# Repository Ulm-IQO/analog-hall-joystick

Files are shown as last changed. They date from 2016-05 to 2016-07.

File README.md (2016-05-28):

# Adjustable, Analog Hall Joystick

This joystick was designed to replace the failing resisitve joystick of a 
PI Micos SMC Corvus eco three-axis stepper motor controller.

The design has a primary XYZ joystick (Apem HF46S10) where the Z axis is 
the rotatable shaft and a secondary stick (Apem BF150A01BK0500) only 
for the Z axis.

Which Z axis is applied at the analog output can be controlled with a switch
while all four signals are available at the analog inputs of the integrated
Teensy 3.x microcontroller board.

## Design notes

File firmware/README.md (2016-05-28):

# Test program
Use Teensyduino to build and upload the test program to a Teensy 3.x
microcontroller board attached to the joystick board.

The values from the serial console can be used to adjust the potentiometers
for the gain and offset stages.

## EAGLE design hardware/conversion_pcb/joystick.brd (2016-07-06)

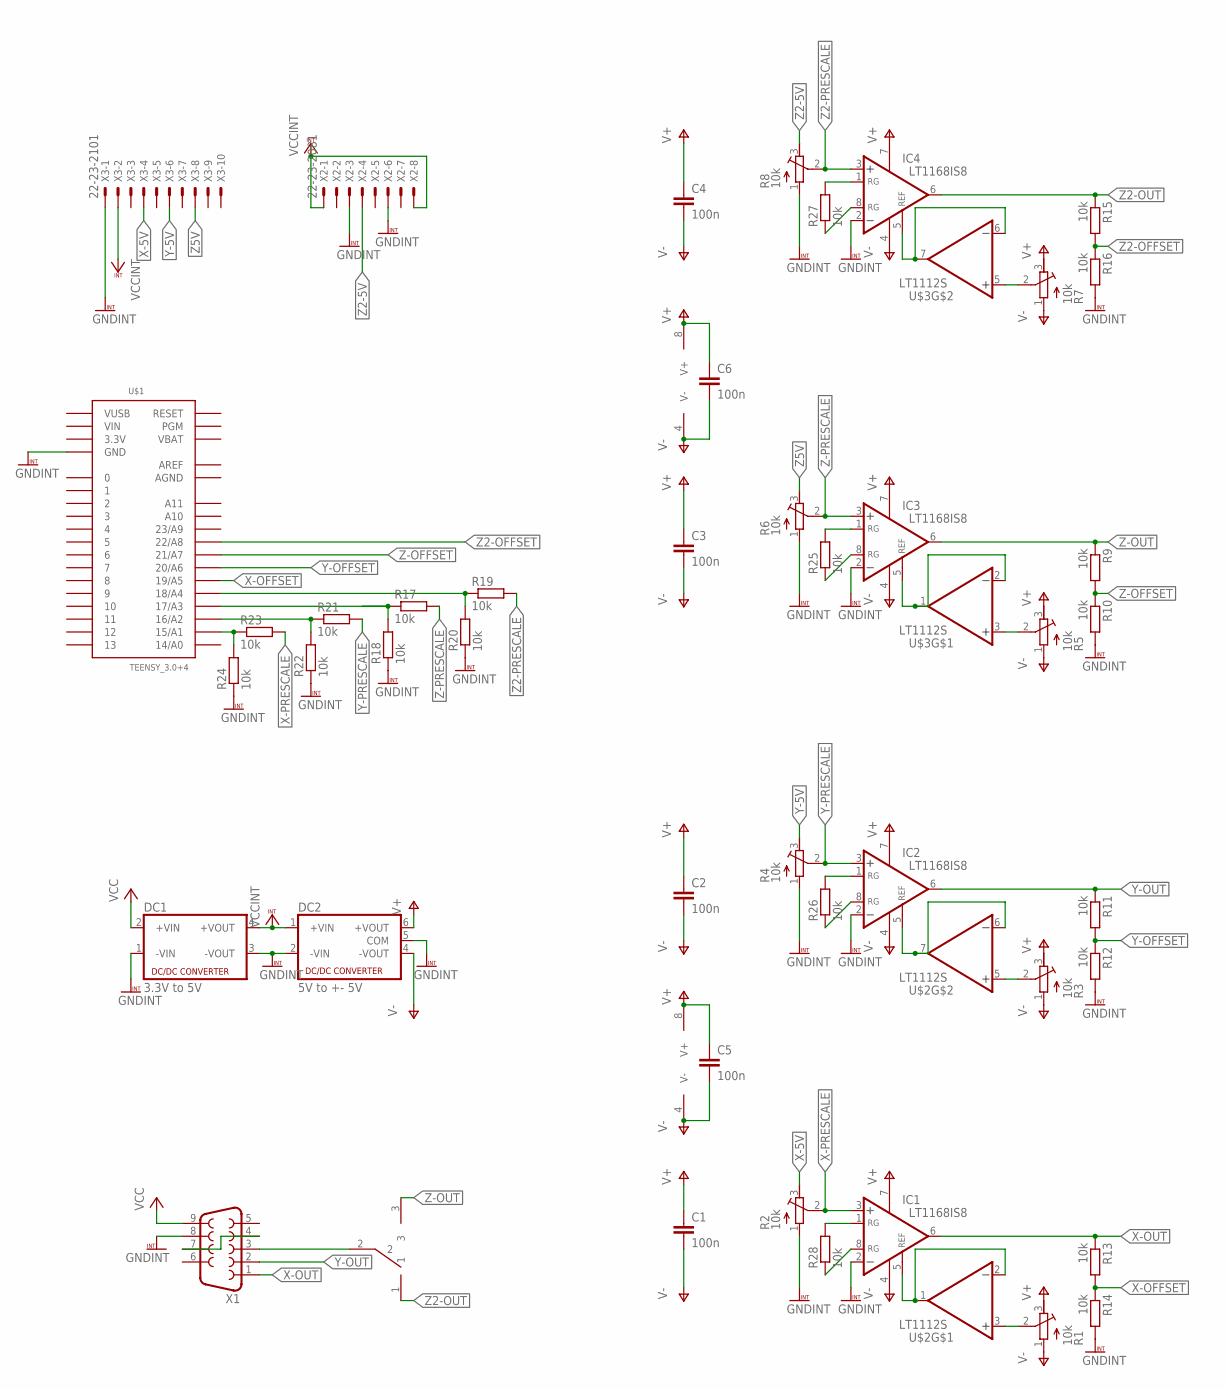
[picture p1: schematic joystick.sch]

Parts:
C1, C2, C3, C4, C5, C6: 100n; C1206
DC1: 3.3V to 5V; NME
DC2: 5V to +- 5V; NMA
IC1, IC2, IC3, IC4: LT1168IS8; SOIC8
R1, R2, R3, R4, R5, R6, R7, R8: 10k; RTRIM64W
R9, R10, R11, R12, R13, R14, R15, R16, R17, R18, R19, R20, R21, R22, R23, R24, R25, R26, R27, R28: 10k; R1206
U$1: TEENSY_3.0+4
U$2, U$3: LT1112S; SOIC8
U$4: MS12ASG40
X1: F09HP
X2: 22-23-2081
X3: 22-23-2101

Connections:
3.3V: U$1.3.3V, U$1.3.3V1 (3.3V)
AGND: U$1.AGND
AREF: U$1.AREF
GNDINT: DC1.1 (-VIN), DC1.3 (-VOUT), DC2.2 (-VIN), DC2.5 (COM), IC1.2 (-IN), IC2.2 (-IN), IC3.2 (-IN), IC4.2 (-IN), R2.1 (A), R4.1 (A), R6.1 (A), R8.1 (A), R10.2, R12.2, R14.2, R16.2, R18.1, R20.1, R22.1, R24.1, U$1.GND, U$1.GND1 (GND), X1.8, X2.3, X2.6, X3.1
unnamed: R1.2 (S), U$2.3 (+IN)
unnamed: R3.2 (S), U$2.5 (+IN)
unnamed: R5.2 (S), U$3.3 (+IN)
unnamed: R7.2 (S), U$3.5 (+IN)
unnamed: IC1.5 (REF), U$2.1 (OUT), U$2.2 (-IN)
unnamed: IC2.5 (REF), U$2.6 (-IN), U$2.7 (OUT)
unnamed: IC3.5 (REF), U$3.1 (OUT), U$3.2 (-IN)
unnamed: IC4.5 (REF), U$3.6 (-IN), U$3.7 (OUT)
unnamed: X1.4, X1.7
unnamed: U$4.2, X1.3
unnamed: R17.1, R18.2, U$1.17/A3
unnamed: R19.1, R20.2, U$1.18/A4
unnamed: R21.1, R22.2, U$1.16/A2
unnamed: R23.1, R24.2, U$1.15/A1
unnamed: IC1.8 (RG), R28.1
unnamed: IC1.1 (RG), R28.2
unnamed: IC2.1 (RG), R26.2
unnamed: IC2.8 (RG), R26.1
unnamed: IC3.1 (RG), R25.2
unnamed: IC3.8 (RG), R25.1
unnamed: IC4.8 (RG), R27.1
unnamed: IC4.1 (RG), R27.2
V+: C1.1, C2.1, C3.1, C4.1, C5.1, C6.1, DC2.6 (+VOUT), IC1.7 (V+), IC2.7 (V+), IC3.7 (V+), IC4.7 (V+), R1.3 (E), R3.3 (E), R5.3 (E), R7.3 (E), U$2.8 (V+), U$3.8 (V+)
V-: C1.2, C2.2, C3.2, C4.2, C5.2, C6.2, DC2.4 (-VOUT), IC1.4 (V-), IC2.4 (V-), IC3.4 (V-), IC4.4 (V-), R1.1 (A), R3.1 (A), R5.1 (A), R7.1 (A), U$2.4 (V-), U$3.4 (V-)
VBAT: U$1.VBAT
VCC: DC1.2 (+VIN), X1.9
VCCINT: DC1.4 (+VOUT), DC2.1 (+VIN), X2.1, X2.8, X3.2
VIN: U$1.VIN
VUSB: U$1.VUSB
X-5V: R2.3 (E), X3.4
X-OFFSET: R13.2, R14.1, U$1.19/A5
X-OUT: IC1.6 (OUT), R13.1, X1.1
X-PRESCALE: IC1.3 (+IN), R2.2 (S), R23.2
Y-5V: R4.3 (E), X3.6
Y-OFFSET: R11.2, R12.1, U$1.20/A6
Y-OUT: IC2.6 (OUT), R11.1, X1.2
Y-PRESCALE: IC2.3 (+IN), R4.2 (S), R21.2
Z2-5V: R8.3 (E), X2.4
Z2-OFFSET: R15.2, R16.1, U$1.22/A8
Z2-OUT: IC4.6 (OUT), R15.1, U$4.1
Z2-PRESCALE: IC4.3 (+IN), R8.2 (S), R19.2
Z5V: R6.3 (E), X3.8
Z-OFFSET: R9.2, R10.1, U$1.21/A7
Z-OUT: IC3.6 (OUT), R9.1, U$4.3
Z-PRESCALE: IC3.3 (+IN), R6.2 (S), R17.2

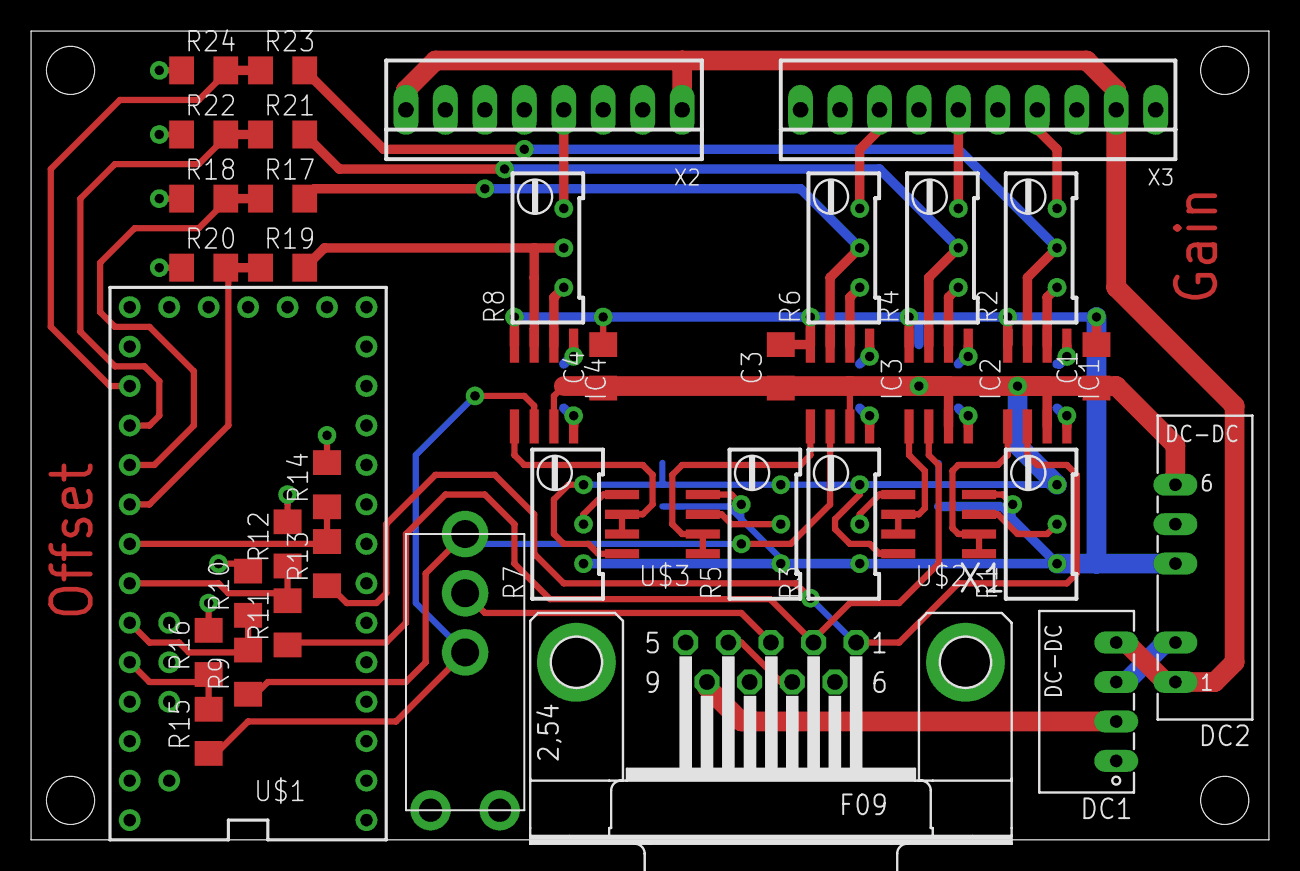
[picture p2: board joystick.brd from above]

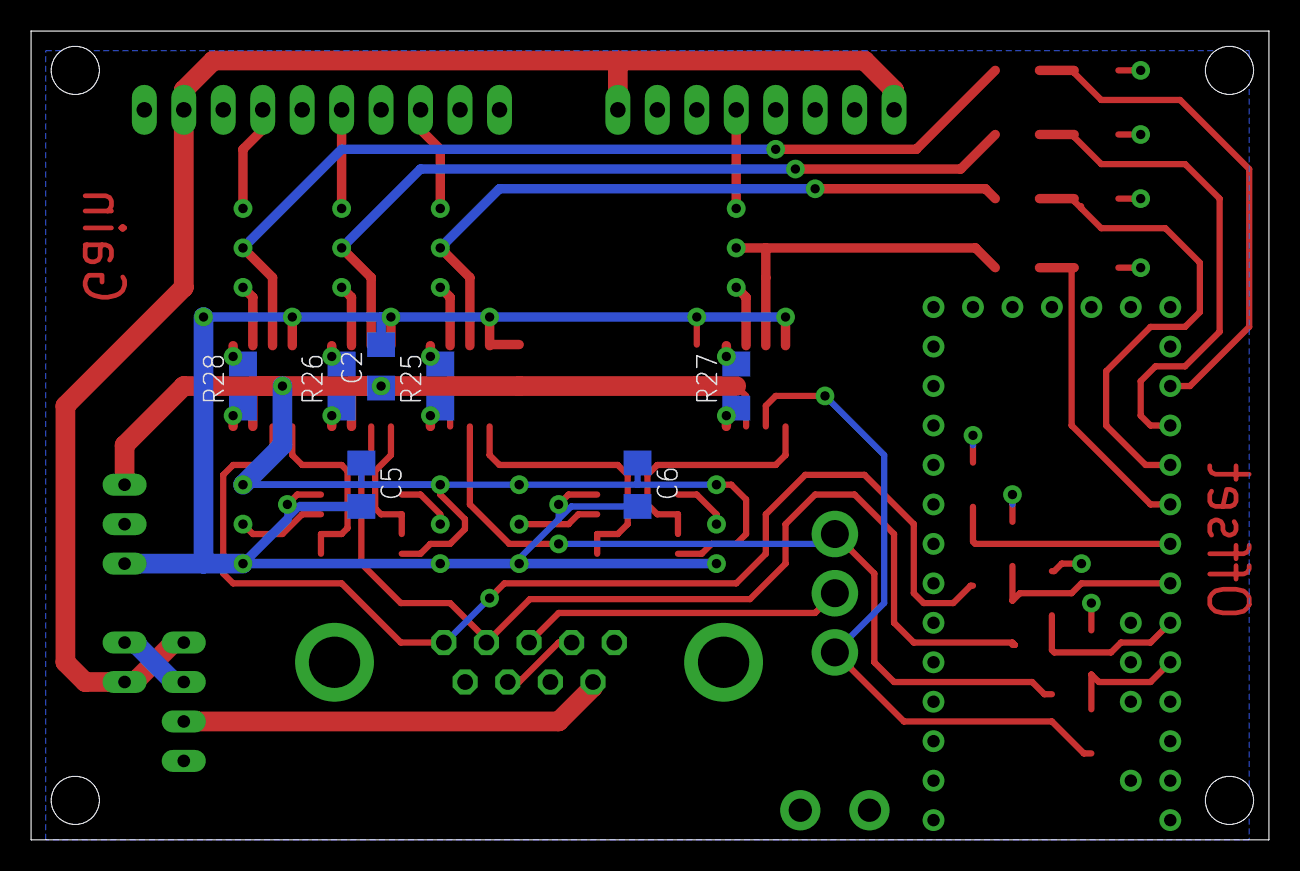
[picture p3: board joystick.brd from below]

Board: 2 copper layers, 79.7 x 52.1 mm, 47 parts (7 on the bottom side), 44 nets.

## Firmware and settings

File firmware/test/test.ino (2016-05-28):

/* Test program to calibrate joystick offset and range */

/* Run with Teensyduino on a Teensy 3.x board */

/* Analog input pins after scaling, before offset stage.
   There is an X axis, Y axis and two Z axes.
*/
int xppin = A1;
int yppin = A2;
int z1ppin = A3;
int z2ppin = A4;

/* Analog input pins after scaling and offset */
int xopin = A5;
int yopin = A6;
int z1opin = A7;
int z2opin = A8;

/* LED */
int ledpin = 13;

void setup() {                
  Serial.begin(38400);

  analogReadResolution(12);

  pinMode(ledpin, OUTPUT); 
  pinMode(xppin,INPUT);
  pinMode(yppin,INPUT);
  pinMode(z1ppin,INPUT);
  pinMode(z2ppin,INPUT);

  pinMode(xopin,INPUT);
  pinMode(yopin,INPUT);
  pinMode(z1opin,INPUT);
  pinMode(z2opin,INPUT);
}

int xpre, ypre, z1pre, z2pre, xpost, ypost, z1post, z2post;

void loop() {
  xpre = analogRead(xppin)*16;
  ypre = analogRead(yppin)*16;
  z1pre = analogRead(z1ppin)*16;
  z2pre = analogRead(z2ppin)*16;
  xpost = analogRead(xopin)*16;
  ypost = analogRead(yopin)*16;
  z1post = analogRead(z1opin)*16;
  z2post = analogRead(z2opin)*16;
  
  Serial.print(xpre);
  Serial.print(" ");
  Serial.print(ypre);
  Serial.print(" ");
  Serial.print(z1pre);
  Serial.print(" ");
  Serial.print(z2pre);
  Serial.print(" ");
  Serial.print(xpost);
  Serial.print(" ");
  Serial.print(ypost);
  Serial.print(" ");
  Serial.print(z1post);
  Serial.print(" ");
  Serial.print(z2post);
  Serial.println();
  
  digitalWrite(ledpin, HIGH);
  delay(250);
  digitalWrite(ledpin, LOW);
  delay(250);
}

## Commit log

2016-05-28 hardware, test firmware and readmes
    [joystick.brd, joystick.sch]
2016-07-06 declutter circuit schematic
    [joystick.brd, joystick.sch]
